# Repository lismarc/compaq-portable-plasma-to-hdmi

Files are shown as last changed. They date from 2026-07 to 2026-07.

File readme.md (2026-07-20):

Hi, this is Marcin @hawix (father) and Kuba @qbus (son).

We are members of the [Polish Society for the Protection of Technical Heritage - Polskie Towarzystwo Ochrony Dziedzictwa Technicznego (PTODT)](https://ptodt.org.pl/). From time to time, we manage to bring old computers back to life. It's our shared passion. We spend time together and learn about electronics, computer science, computer system architecture, and their history. 

We summarize the results of our work at events organized by PTODT, called KWAS.

---

In 2025, Kuba received an iconic **Compaq Portable III** computer from Szymon @sajmosia. The computer was complete, but its plasma screen was broken.

We decided to resurrect this computer. 
The project presented here is the result of our work. The broken plasma screen is beyond repair, but we came up with the idea of replacing the screen with a modern LCD screen with an HDMI connector. 

To achieve this, we analyzed the signals reaching the display. We designed a simple FPGA-based circuit that decodes signals and converts them into an HDMI stream.

---

On Saturday, June 26, 2025, the 40th KWAS meeting took place in Katowice, where we presented our joint adventure of restoring a donated computer. 
**[You can watch it here, paste a link]** *(Note: insert video link here)*. There, we discuss how it works.

We know that many Compaq Portable III computers experience screen problems for various reasons. We hope this project will help bring your computer back to life.

### We are sharing all project files:

* 📁 **`fpga-tang-nano`**  
  Verilog source code for the Tang Nano 9K platform. This is a very inexpensive circuit with a low entry threshold for amateurs. The FPGA configuration is written in the [Gowin IDE](https://www.gowinsemi.com/en/support/home). You can build a bitstream for this circuit yourself and transfer it to the flash memory via USB-C.

* 📁 **`Schematics-kicad`**  
  Schematic of a board with a voltage converter from 5V logic signals from the Compaq to the 3.3V logic required by the Tang Nano. The board is designed as a shield that attaches to the back of the Tang Nano 9K to minimize space and fit inside the display case. It also includes a USB connector for powering the display. The catalog also includes ready-made Gerber files, which you can submit to PCBWay or similar companies.

* 📁 **`adapter-fussion360`**  
  3D printable LCD screen adapter design. We used dispaly ELCROW 10,1" 1280x800  that can perfectly can be fitted into CPIII disaply panel.

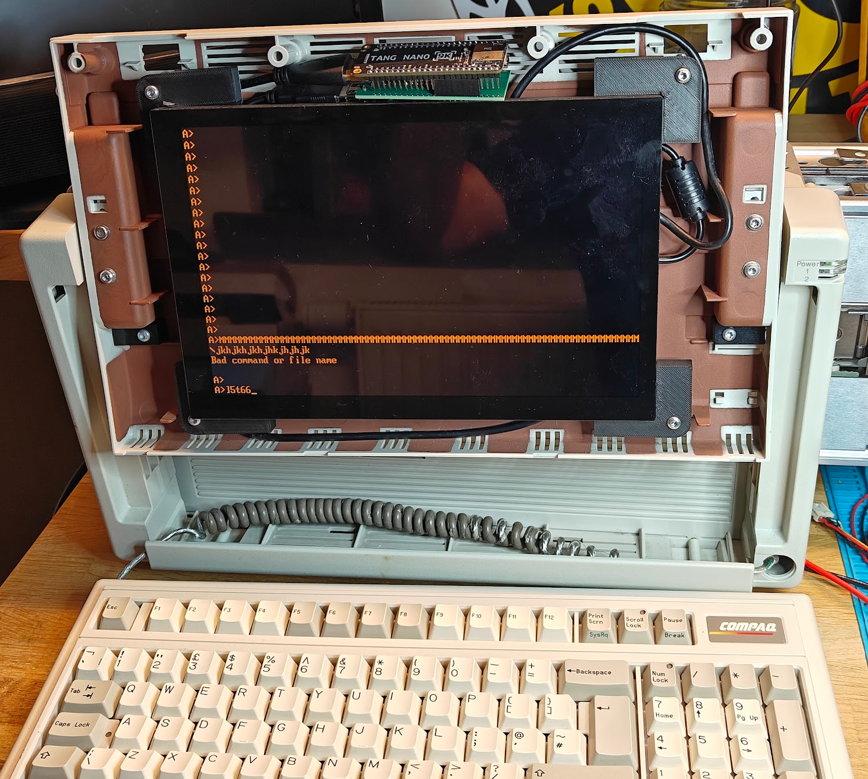
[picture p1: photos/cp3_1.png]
See how it looks like


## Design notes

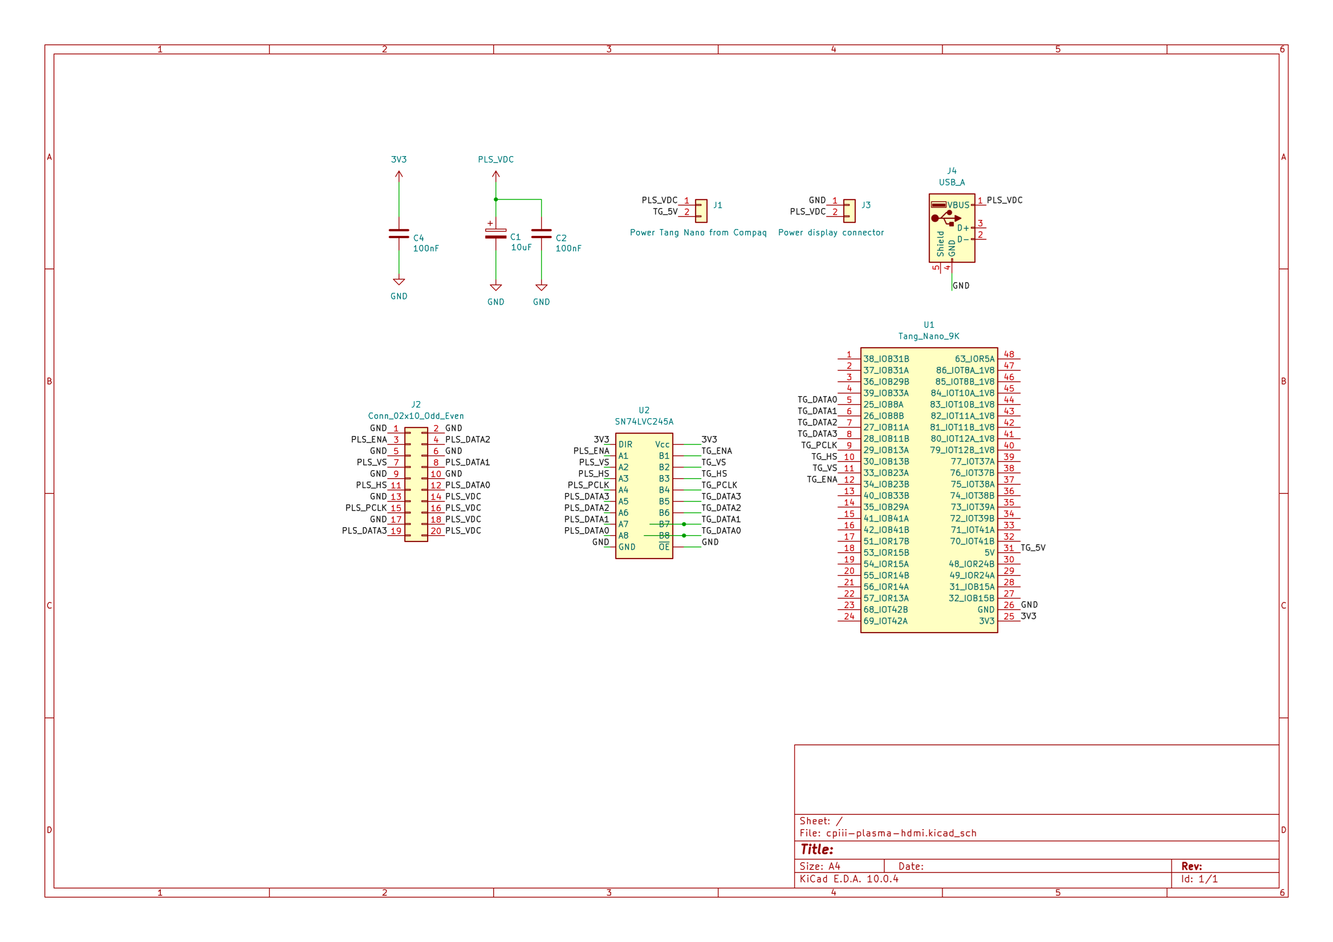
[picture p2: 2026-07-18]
photos/schematics.png

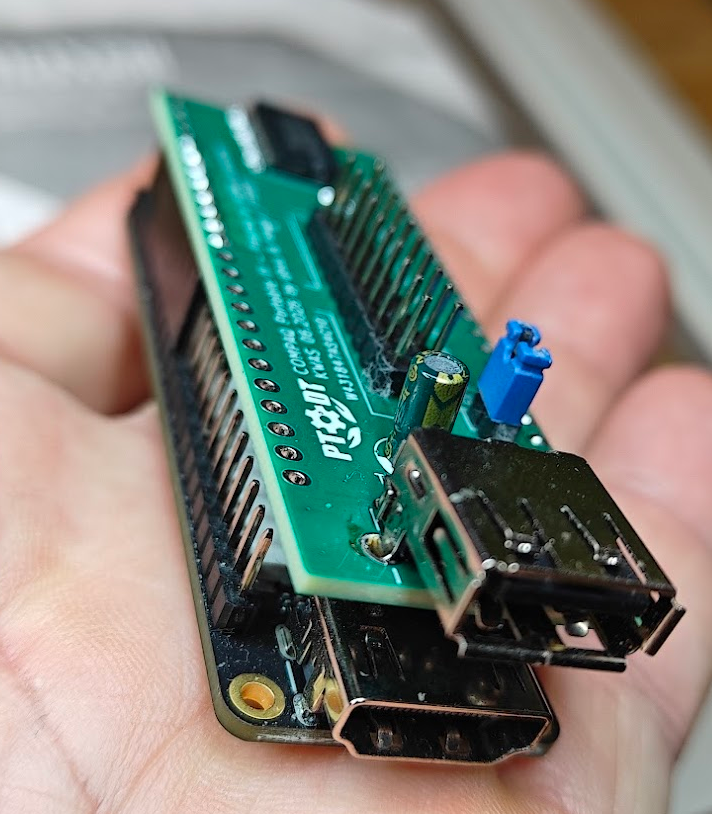
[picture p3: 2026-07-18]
photos/tang-nano.png

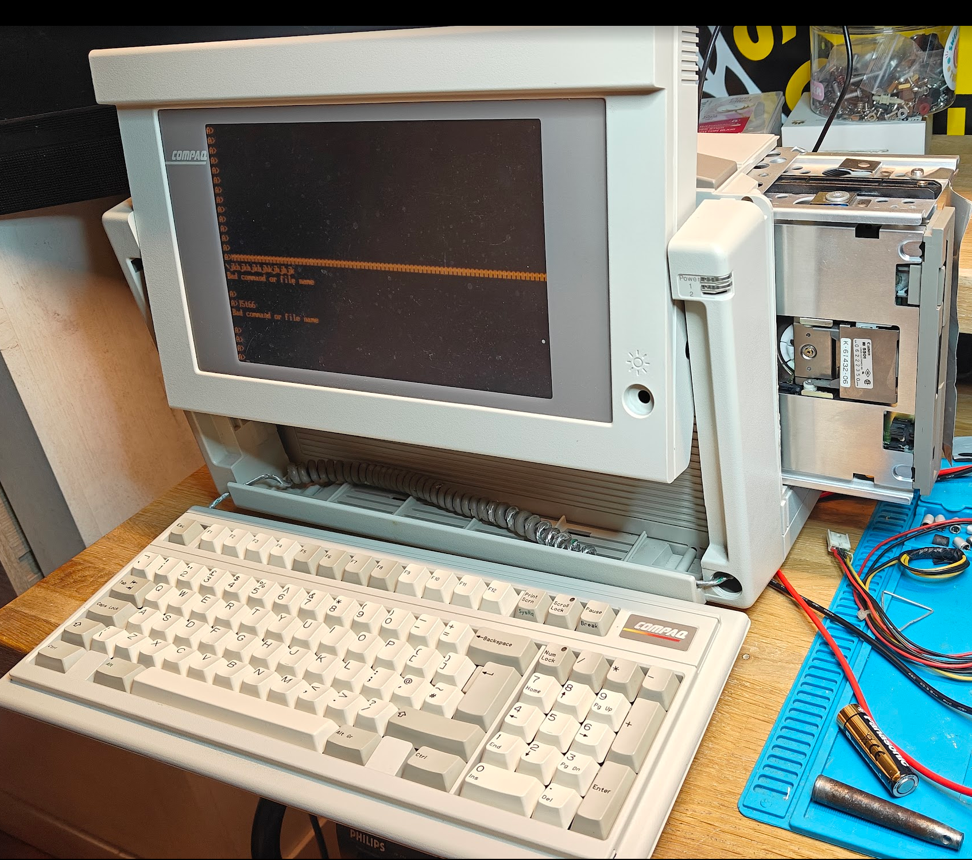
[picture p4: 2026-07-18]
photos/cp3_2.png

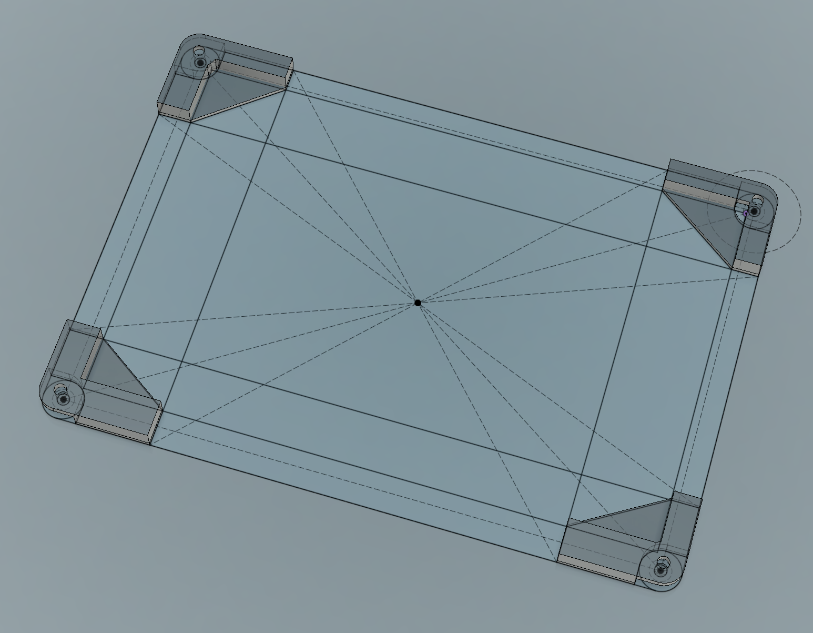
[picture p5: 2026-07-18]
photos/display-handlers.png

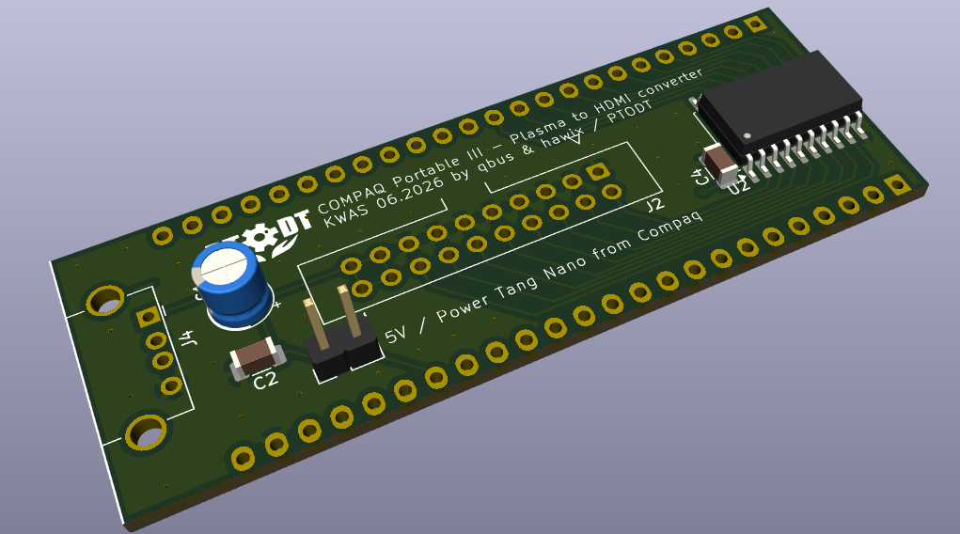
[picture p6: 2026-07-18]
photos/adapter-pcb.png

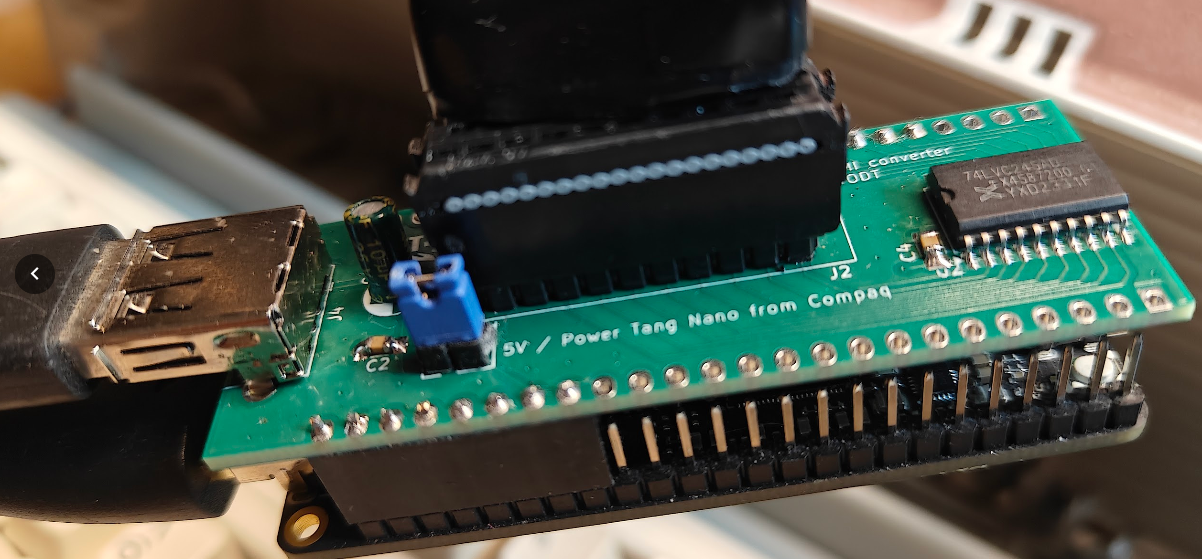
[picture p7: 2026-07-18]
photos/tang-nano_1.png

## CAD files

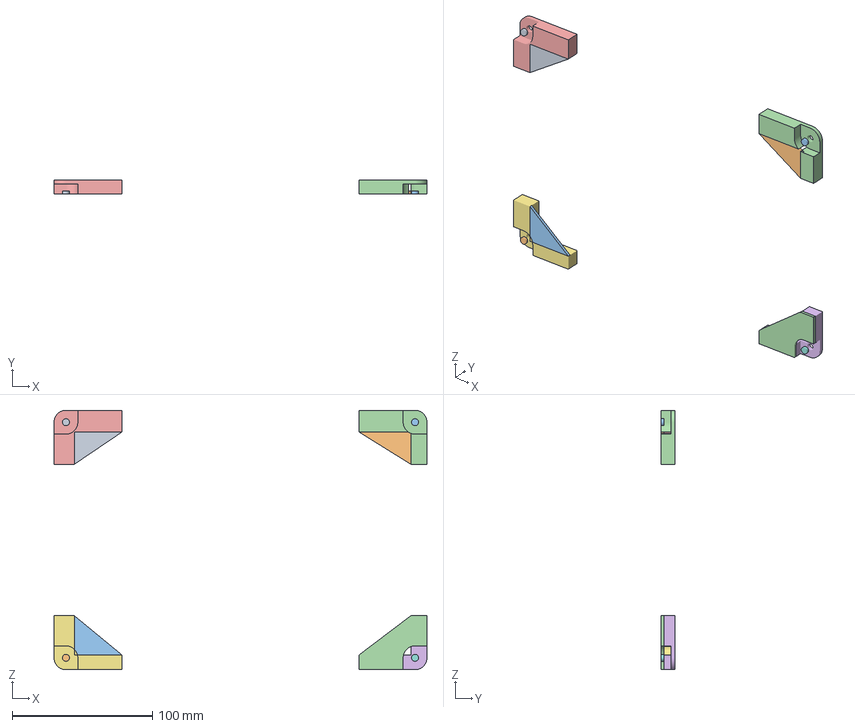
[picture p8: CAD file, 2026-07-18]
adapter-fussion360/CP3-HDMI-Handle.3mf
266.0 x 10.0 x 185.0 mm

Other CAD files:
adapter-fussion360/CP3-HDMI-Handle.stl

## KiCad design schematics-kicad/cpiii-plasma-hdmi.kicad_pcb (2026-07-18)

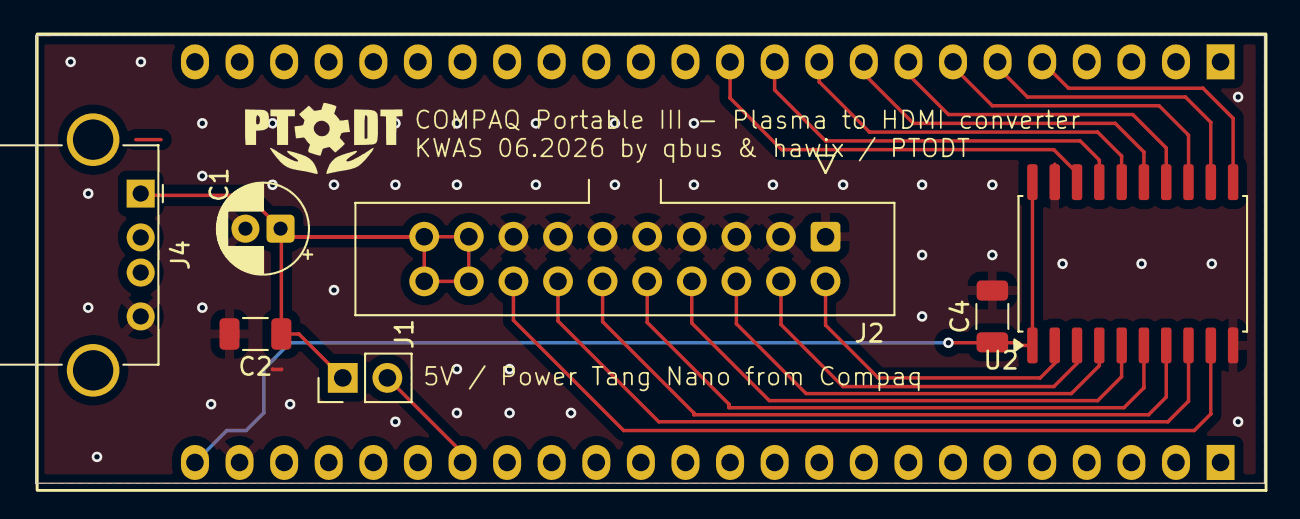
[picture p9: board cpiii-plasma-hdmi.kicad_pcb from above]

Board: 2 copper layers, 70.0 x 25.5 mm, 9 parts (0 on the bottom side), 20 nets.

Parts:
C1: 10uF; CP_Radial_D5.0mm_P2.00mm
C2, C4: 100nF; C_1206_3216Metric
J1: Power Tang Nano from Compaq; PinHeader_1x02_P2.54mm_Vertical
J2: PLASMA_CONNECTOR; IDC-Header_2x10-1MP_P2.54mm_Latch6.5mm_Vertical
J4: USB_A; USB_A_Stewart_SS-52100-001_Horizontal
U1: Tang_Nano_9K; DIP-48_TangNano9K
U2: SN74LVC245A; SOIC-20W_7.5x12.8mm_P1.27mm
a: LOGO; ptodt

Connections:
3V3: C4.1, U1.25 (3V3), U2.1 (DIR), U2.20 (Vcc)
/PLS_DATA0: J2.16, U2.9 (A8)
/PLS_DATA1: J2.14, U2.8 (A7)
/PLS_DATA2: J2.12, U2.7 (A6)
/PLS_DATA3: J2.10, U2.6 (A5)
/PLS_ENA: J2.2, U2.2 (A1)
/PLS_HS: J2.6, U2.4 (A3)
/PLS_PCLK: J2.8, U2.5 (A4)
/PLS_VS: J2.4, U2.3 (A2)
/TG_5V: J1.2, U1.31 (5V)
/TG_DATA0: U1.5 (25_IOB8A), U2.11 (B8)
/TG_DATA1: U1.6 (26_IOB8B), U2.12 (B7)
/TG_DATA2: U1.7 (27_IOB11A), U2.13 (B6)
/TG_DATA3: U1.8 (28_IOB11B), U2.14 (B5)
/TG_ENA: U1.12 (34_IOB23B), U2.18 (B1)
/TG_HS: U1.10 (30_IOB13B), U2.16 (B3)
/TG_PCLK: U1.9 (29_IOB13A), U2.15 (B4)
/TG_VS: U1.11 (33_IOB23A), U2.17 (B2)
GND: C1.2, C2.2, C4.2, J2.1, J2.3, J2.5, J2.7, J2.9, J2.11, J2.13, J2.15, J4.4 (GND), U1.26 (GND), U2.10 (GND), U2.19 (~OE)
PLS_VDC: C1.1, C2.1, J1.1, J2.17, J2.18, J2.19, J2.20, J4.1 (VBUS)
